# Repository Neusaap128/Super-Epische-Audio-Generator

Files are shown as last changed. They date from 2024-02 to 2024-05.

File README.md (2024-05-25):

**CubeIDEProject:** Deze bevat de code die we op de dev board geschreven hebben voor we overschakelde naar de PCB \
**FiltersWavFiles:** Bevat de C-code en de wav files van filters \
**KicadProject:** De technische schema's van onze PCB en hoe we alles hebben aangesloten aan elkaar \
**SEAG_F:** De implementatie op de STM32F722RC (wat we uitendelijk gebruikt hebben) \
**Super Epische Audio Generator:** Bevat Datasheet per onderdeel, PCB benodigheden, Tekst documenten voor Seminarie waar ook het eindverslag van alles staat

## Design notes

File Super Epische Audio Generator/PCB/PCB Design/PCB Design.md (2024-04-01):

- - -

### General

layer 1 GND plane
layer 2 VCC plane, split digital en analog op de PCB, en teken dan een plane me 3v3 digitaal, en 3v3 analog, dan kan onkoppeling met via's. das kei goe gezien!

### Power Supply

```mermaid

flowchart LR
supply("5V Supply")
digital("Digital Supply")
analog3("Analog 3V3 Supply")
analog2("Analog 2V Supply")
supply-- 3V3 LDO \n Voltage Regulator --> digital
supply -- 3V3 LDO \n Voltage Regulator --> analog3
analog3 -- 2V5 LDO \n Voltage Regulator --> analog2
```

### Audio Filtering

Use difference IC's for input and output buffers.

### Codec

HPSEL = 10 JD2

Single ended Non inverting input PGA should be connected to VMID.
(Closed when LMP2=0 & LMP3=0, or when muted)

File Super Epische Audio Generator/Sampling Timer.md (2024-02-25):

- - -

Sampling Rate counter example

$f_s$ = 44.000Khz
$T_s$ = 1/f = 22.72µs = 22727.27ns

Prescaler bus = /1
Prescaler timer = /1 

Timer Clock $f_{clk}$ = 170Mhz
Timer period $T_{clk}$ = 5.88ns

clockstrikes = $\frac{T_s}{T_{clk}} = \frac{f_{clk}}{T_s}$ = 3864

--- Will's notes ---

CLK settings
200MHZ
APB1 pre /4
APB2 pre /2
=> timer 1 clock = 100MHz

calculation
100MHz => periode van 10ns
elke 500ms
500ms / 10ns = 50 000 000
50 000 000 => count value

48MHz => 21ns
na 5sec
5000 / 21ns = 238 095 238

Prescaler (ni nodig as u waarde in die variable past)
in 1 seconde 100 000 000 pulses
in 1 seconde      10 000 pulses    ( / 10000 ) = prescaler

autoreload aanzette hangt af van applicatie
couter mode => down
prescaler 0
counter period  = 50000 - 1 (0 is ook een waarde)
(zorgen dat in een 32bit register past)

turn NVIC on in timer menu en system core tab

SYS timebase source timer 1

code
HAL_TIM_Base_Start_IT (vergeet IT ni !!!)

if (htim->Instance == TIM2) {
     //Plaats uw code hier
}

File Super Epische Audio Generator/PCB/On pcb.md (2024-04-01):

- [ ] ledbar
- [ ] led-select bar
- [ ] togel
- [ ] codec
- [ ] STM 
- [ ] voltage regulator
- [ ]

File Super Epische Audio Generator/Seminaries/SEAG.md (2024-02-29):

- - -

### Onderwerp 
We gaan voor ons IB3 project een audio effect generator maken. We zijn 3 elektronica-ICT studenten, we bouwen dit project verder op onze reeds vergaarde kennis van een voorgaand vak namelijk Digital Signal Processing (DSP). We gaan een audio signaal binnen lezen, dit signaal dan vervormen aan de hand van filters en terug naar buiten brengen via een audio jack.

### Probleem omschrijving
Niet gemoduleerde instrument klanken kunnen eentonig klinken. Om dit op te lossen gaan we aan de hand van DSP de audio transformeren. We willen een gemakkelijke user interface hebben waarmee je eenvoudig de effecten kunt instellen. 

Wanneer de audio luid en duidelijk hoorbaar is door een speaker, na vervorming, kunnen we spreken van een geslaagd project!

### Technische beschrijving
Voor de audio wordt ingelezen wordt deze gebuffered en gefiltert. De audio digitaliseren we via een codec, deze sampled de audio naar 24 bit waarden. Deze worden vervolgens doorgestuurd naar een STM32 controller via I²S verbinding. De codec wordt ingesteld via I²C. De STM32 microcontroller doet DSP om de audio te vervormen. Vervolgens word de vervormende digitale audio terug gestuurd naar de codec, dia het via een Digital Analog Converter (DAC) terug omzet naar een hoorbaar electrisch signaal.

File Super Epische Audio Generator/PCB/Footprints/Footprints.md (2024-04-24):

- - -

### Power Supply

3.3V LDO voltage regulator:
https://www.mouser.be/ProductDetail/Diodes-Incorporated/AP7365-33YG-13?qs=abZ1nkZpTuOMWfgz6BLgPQ%3D%3D

2.5V LDO voltage regulator (Not used):
https://www.mouser.be/ProductDetail/Diodes-Incorporated/AP7365-25YG-13?qs=abZ1nkZpTuOUTso75Vvnyg%3D%3D

ESD Protection diode 6.5V
https://www.mouser.be/ProductDetail/Diodes-Incorporated/SMAJ6.5A-13-F?qs=gaDBXWSqsDCMFmRk5%252BbksQ%3D%3D

Reverse voltage shotkey diode
https://www.mouser.be/ProductDetail/Panjit/SX33L_R1_00001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.
### MCU

stm32 g431RB:
https://www.mouser.be/ProductDetail/STMicroelectronics/STM32G431RBT3?qs=GedFDFLaBXGyvb87LV0VhQ%3D%3D

STM32 F722RCT6:
https://www.mouser.be/ProductDetail/STMicroelectronics/STM32F722RCT6?qs=Mv7BduZupUiR0Y60TnwX8g%3D%3D

Crystal:
https://www.mouser.be/ProductDetail/Diodes-Incorporated/FW2500025Z?qs=Rp3RbKSfAt1J3JBNemv8gQ%3D%3D

### Audio Filtering

Audio op-amp
https://www.mouser.be/ProductDetail/Texas-Instruments/LM833DR?qs=Ze4%2FuFuz19LM5Pd0zMa%2Fjg%3D%3D 

Audio codec
https://www.digikey.be/en/products/detail/cirrus-logic-inc/WM8960CGEFL-V/5036712

# IO

Shift Register
https://www.mouser.be/ProductDetail/Nexperia/74HC595D-Q100118?qs=1sbE9T7hb3auqb4IeRpHgw%3D%3D

Screw terminal 3
https://www.mouser.be/ProductDetail/TE-Connectivity/282834-3?qs=A%252Bip%252BNCYi6M69kAjqV38yA%3D%3D

### Miscellaneous

47uF cap
https://www.vishay.com/docs/40189/t58.pdf

- Weerstanden smd 0805
- Caps smd 0805
- Shift registers 
- Ledjes THT en SMD
- Micro usb-b  female connector
- Feritte bead 
- Jumper cables
- St link programmer
- Male headers
- Audio female jacks
- Pot meters
- Toggles
- SPDT 
- Eigen PCB

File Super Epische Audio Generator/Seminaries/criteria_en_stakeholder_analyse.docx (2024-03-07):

# Audio Effect Generator

Doelstelling:

We gaan een audio effect generator maken met zelf gecreëerde effecten. We gaan simpel beginnen met een audio input via AUX binnen te lezen. Het inkomend audiosignaal via een STM controller bewerken en dan terug via een AUX naar buiten brengen. Op de output kan dan een speaker worden aangesloten om het bewerkt signaal te beluisteren.

Onze minimum criteria zijn:

- Audio input/output via AUX binnen lezen.
- ADC en DAC .
- Aansturen via een controller developer board.
- I / O knoppen om de gecreëerde effecten aan te sturen.
- Zelf de volgende effecten creëren:
- Bass regelen
- Treble
- Delay
- chorus

Als we klaar zijn met de minimum criteria gaan we ons project nog uitbereide als volgt:

- Een PCB zelf maken
- Meerdere inputs
- Nog extra effecten creëren:
  - Reverb
  - Distortion
  - Loop
  - Wahwah
- Betere DAC/ADC codec

Beknopte stakeholder analyse:

We gaan de stakeholder analyse doen aan de hand van volgende vier vragen:

- Wie zijn je stakeholders en wat willen ze?

Onze stakeholder is meneer Pauwels (key stakeholder). Hij zal ons opvolgen en begeleiden doorheen het semester. Hij wilt dat we op een gelijk tempo elke week in het labo vooruitgang boeken om zo tot een afgewerkt product te komen. De uitgebreide stakeholders (keep satisfied) is ook nog de jury die ons gaat evalueren tijdens onze demo/presentatie. Doordat zij alleen onze eind versie zullen zien tijdens onze demo is het voornamelijk belangrijk dat we tegen dan een mooi verzorgde demo kunnen geven.

Uiteraard zijn wij als developers ook key stakeholders. Bij ons is het belangrijk dat we tegen de uiterste deadline onze minimum criteria sowieso kunnen laten zien en (hopelijk) ook enkele uitbereidingen. Dit willen we bereiken door als team wekelijks progressie te maken en duidelijk te communiceren aan de hand van scrum meetings tijdens onze 4u in het labo en onze meetings op zondag.

- Waarom willen ze dit?

Meneer Pauwels wilt dit door dat hij vooruitgang wilt zien tijdens onze project uren iedere week, doordat hij ook een cijfer geeft op onze permanente evaluatie.

De jury gaat alleen ons eind project zien dus voor hen is het alleen belangrijk dat we een mooi eindresultaat hebben.

Wij als developers zijn begaan met heel het project dus willen een goed verloop en eindresultaat.

- Hoe kunnen ze invloed uitoefenen op je traject?

Meneer Pauwels kan invloed uitoefenen door ons raad te geven doorheen het semester. Hij bepaald ook onze permanente evaluatie en ons eind resultaat.

De jury heeft alleen invloed op ons eind resultaat.

Wij hebben invloed over heel het traject. Door de opties dat we kiezen en onze werkhouding doorheen het traject.

- Hoe kan je jouw stakeholders zo goed mogelijk managen?

Meneer Pauwels kunnen we managen door zo goed mogelijk met hem te communiceren doorheen het traject.

De jury kunnen we moeilijk managen doordat we nog niet weten wie er in de jury zou zitten. We kunnen hen enkel managen door een goed voorbereide presentatie te geven en hun op het moment van onze demo om ver te blazen.

Wij kunnen ons zelf managen door goede afspraken te maken en duidelijk onderling te communiceren. Zo komen we al elke week 4u samen tijdens onze project uren en dan bellen we ook op regelmatige basis in Discord met mekaar.

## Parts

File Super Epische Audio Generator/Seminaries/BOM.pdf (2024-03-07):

# BOM

## Power Supply

3.3V LDO voltage regulator: https://www.mouser.be/ProductDetail/Diodes-Incorporated/AP7365-33YG-13?qs=abZ1nkZpTuOMWfgz6BLgPQ%3D%3D (https://www.mouser.be/ProductDetail/Diodes-Incorporated/AP7365-33YG-13?qs=abZ1nkZpTuOMWfgz6BLgPQ%3D%3D)

2.5V LDO voltage regulator (Not used): https://www.mouser.be/ProductDetail/Diodes-Incorporated/AP7365-25YG-13?qs=abZ1nkZpTuOUTso75Vvnyg%3D%3D (https://www.mouser.be/ProductDetail/Diodes-Incorporated/AP7365-25YG-13?qs=abZ1nkZpTuOUTso75Vvnyg%3D%3D)

## MCU

stm32 g431RB:
https://www.mouser.be/ProductDetail/STMicroelectronics/STM32G431RBT3?qs=GedFDFLaBXGyvb87LV0VhQ%3D%3D (https://www.mouser.be/ProductDetail/STMicroelectronics/STM32G431RBT3?qs=GedFDFLaBXGyvb87LV0VhQ%3D%3D)

STM32 F722RCT6:
https://www.mouser.be/ProductDetail/STMicroelectronics/STM32F722RCT6?qs=Mv7BduZupUiR0Y60TnwX8g%3D%3D (https://www.mouser.be/ProductDetail/STMicroelectronics/STM32F722RCT6?qs=Mv7BduZupUiR0Y60TnwX8g%3D%3D)

## Audio Filtering

Audio op-amp
https://www.mouser.be/ProductDetail/Texas-Instruments/LM833DGKR?qs=Ze4%2FuFuz19JOpjm8ASDMUA%3D%3D (Footprint not downloaded (https://www.mouser.be/ProductDetail/Texas-Instruments/LM833DGKR?qs=Ze4%2FuFuz19JOpjm8ASDMUA%3D%3D) yet)

Audio codec

## Miscellaneous

Weerstanden smd 0805
Caps smd 0805
Shift registers
Ledjes THT en SMD
Micro usb-b female connector Feritte bead

Jumper cables
St link programmer
Male headers
Audio female jacks
Pot meters
Toggles
SPDT
Eigen PCB

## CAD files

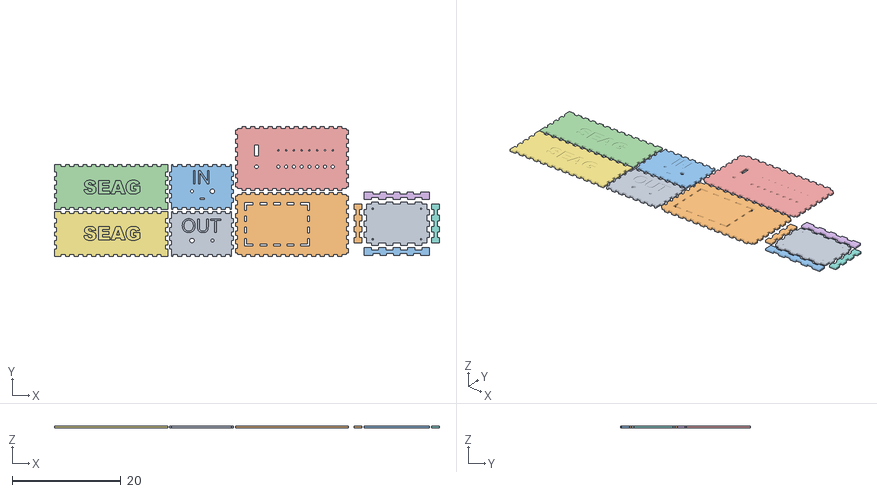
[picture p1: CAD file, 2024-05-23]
Super Epische Audio Generator/2D tekeningen/SEAGdoos.obj
70.7 x 23.9 x 0.4

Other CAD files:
Super Epische Audio Generator/2D tekeningen/SEAGDoos.dwg
Super Epische Audio Generator/2D tekeningen/SEAG_doos.dxf

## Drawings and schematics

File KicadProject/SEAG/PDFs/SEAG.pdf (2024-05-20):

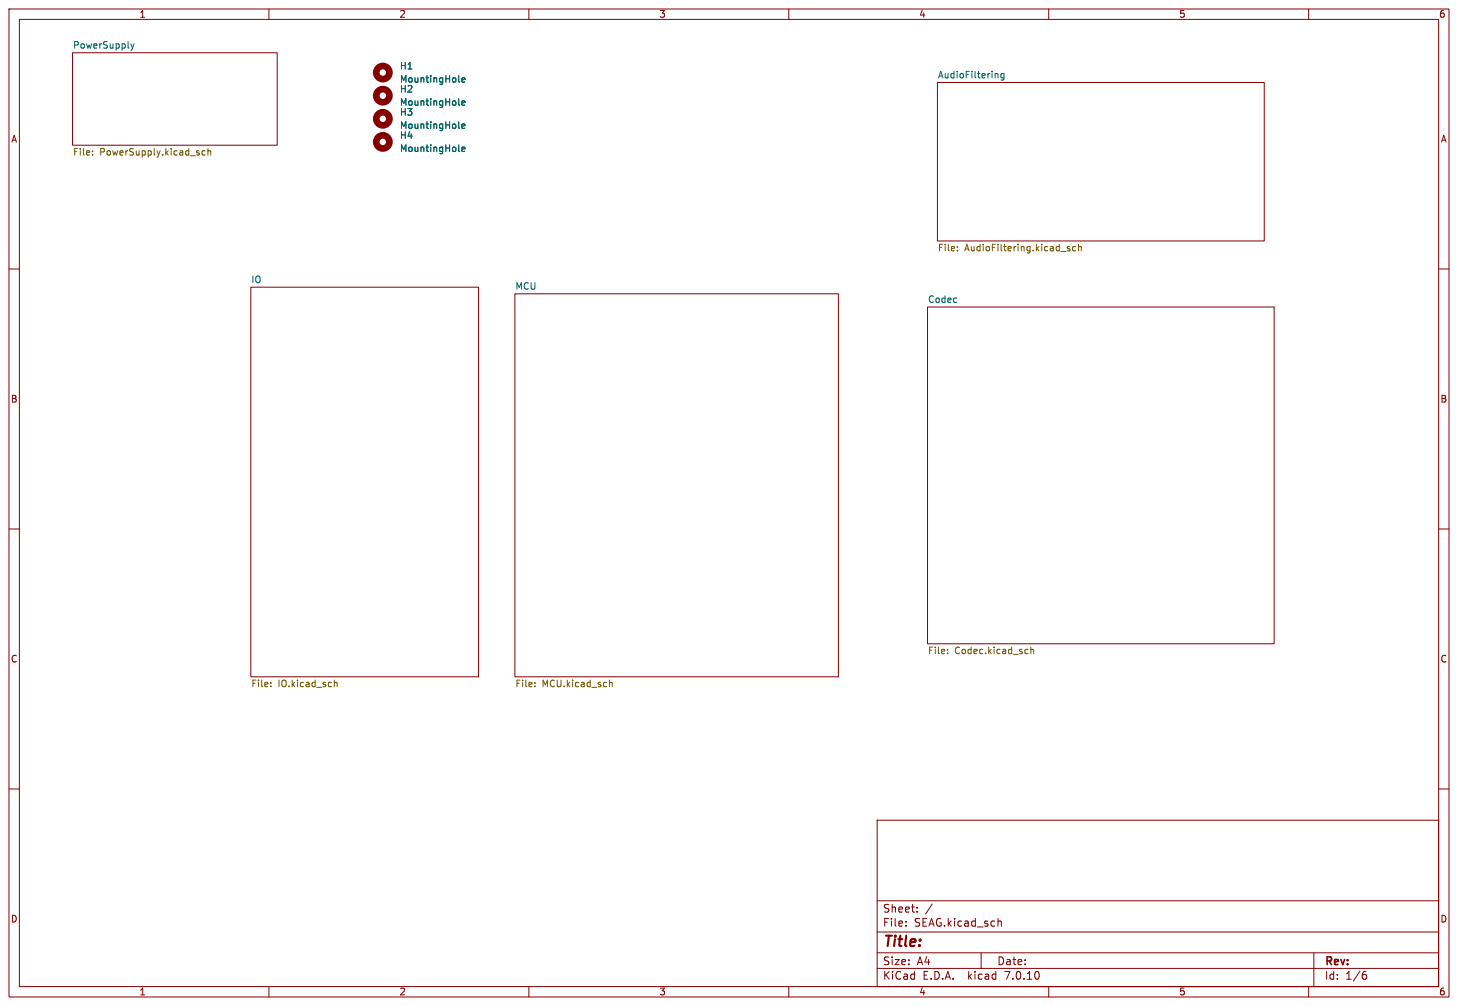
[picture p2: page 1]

H1 MountingHole H3 MountingHole H4 MountingHole H2 MountingHole

AudioFiltering File: AudioFiltering.kicad_sch MCU

Id: 1/6 Title: File: SEAG.kicad_sch Sheet: /

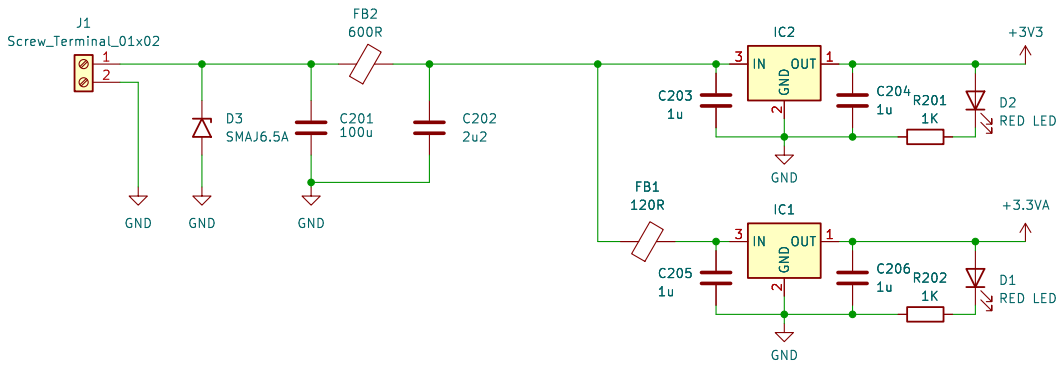
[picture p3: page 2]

File: PowerSupply.kicad_sch Sheet: /PowerSupply/
Id: 2/6 Title: Power Supply

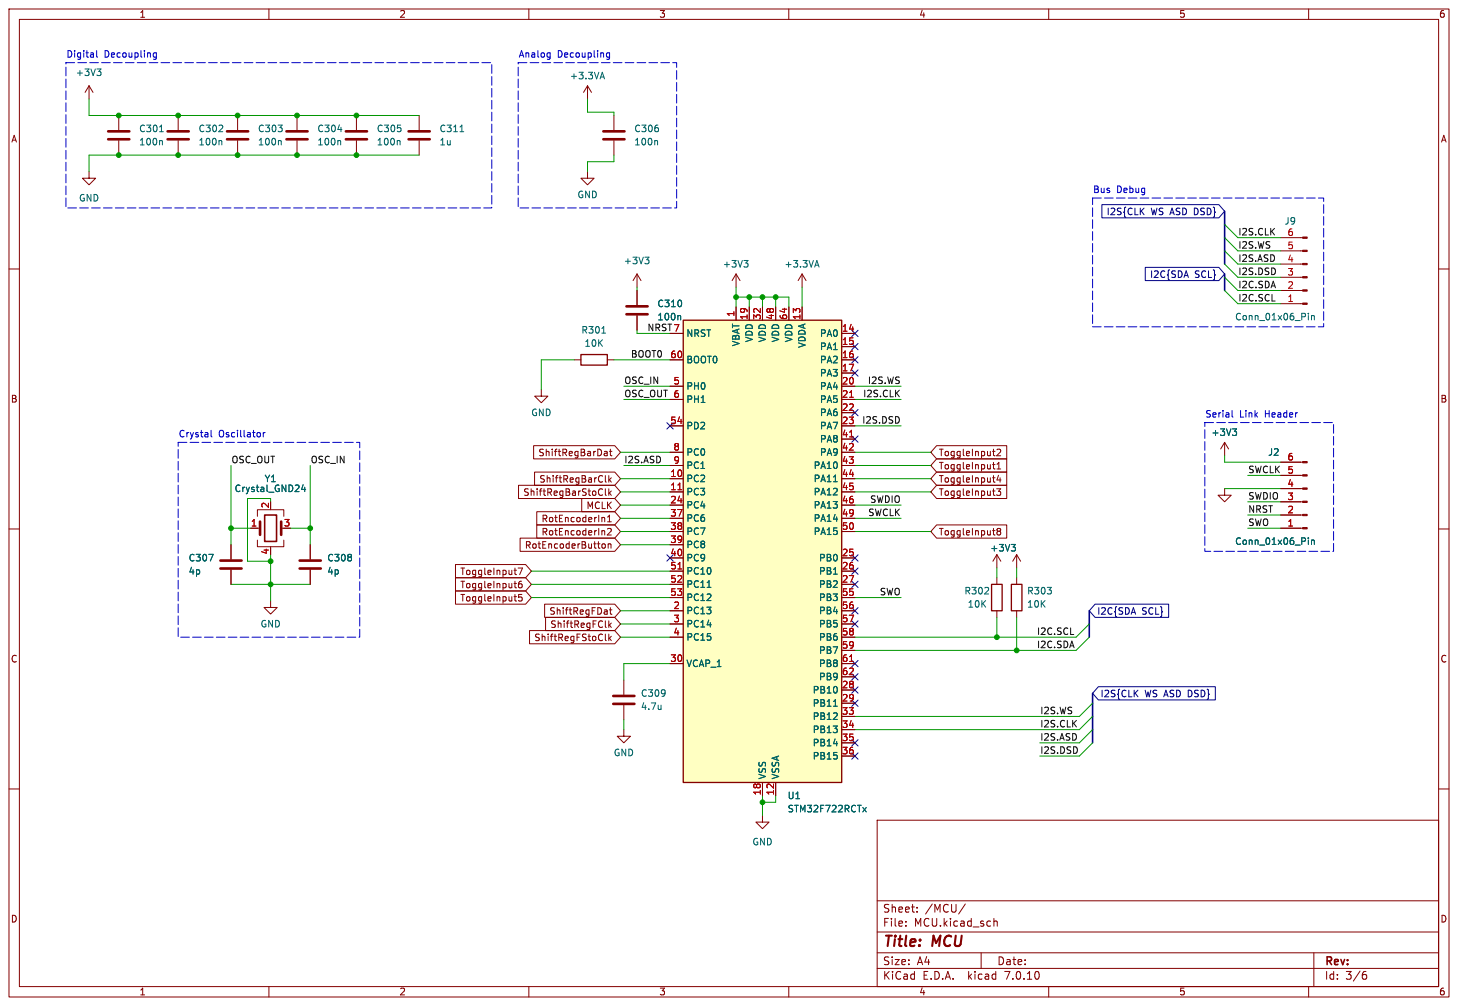
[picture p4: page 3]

I2S{CLK WS ASD DSD}

1 PC2 10 PC3 11 VSSA 12 VDDA 13 PA0 14 PA1 15 PA2 16 PA3 17 VSS 18 VDD 19 PC13 2 PA4 20 PA5 21 PA6 22 PA7 23 PC4 24 PB0 25 PB1 26 PB2 27 PB10 28 PB11 29 PC14 3 VCAP_1 30 VDD 32 PB12 33 PB13 34 PB14 35 PB15 36 PC6 37 PC7 38 PC8 39 PC15 4 PC9 40 PA8 41 PA9 42 PA10 43 PA11 44 PA12 45 PA13 46 VDD 48 PA14 49 PH0 5 PA15 50 PC10 51 PC11 52 PC12 53 PD2 54 PB3 55 PB4 56 PB5 57 PB6 58 PB7 59 PH1 6 BOOT0 60 PB8 61 PB9 62 VDD 64 NRST 7 PC0 8 PC1 9 U1STM32F722RCTx

1 PC2 10 PC3 11 VSSA 12 VDDA 13 PA0 14 PA1 15 PA2 16 PA3 17 VSS 18 VDD 19 PC13 2 PA4 20 PA5 21 PA6 22 PA7 23 PC4 24 PB0 25 PB1 26 PB2 27 PB10 28 PB11 29 PC14 3 VCAP_1 30 VDD 32 PB12 33 PB13 34 PB14 35 PB15 36 PC6 37 PC7 38 PC8 39 PC15 4 PC9 40 PA8 41 PA9 42 PA10 43 PA11 44 PA12 45 PA13 46 VDD 48 PA14 49 PH0 5 PA15 50 PC10 51 PC11 52 PC12 53 PD2 54 PB3 55 PB4 56 PB5 57 PB6 58 PB7 59 PH1 6 BOOT0 60 PB8 61 PB9 62 VDD 64 NRST 7 PC0 8 PC1 9 +3V3

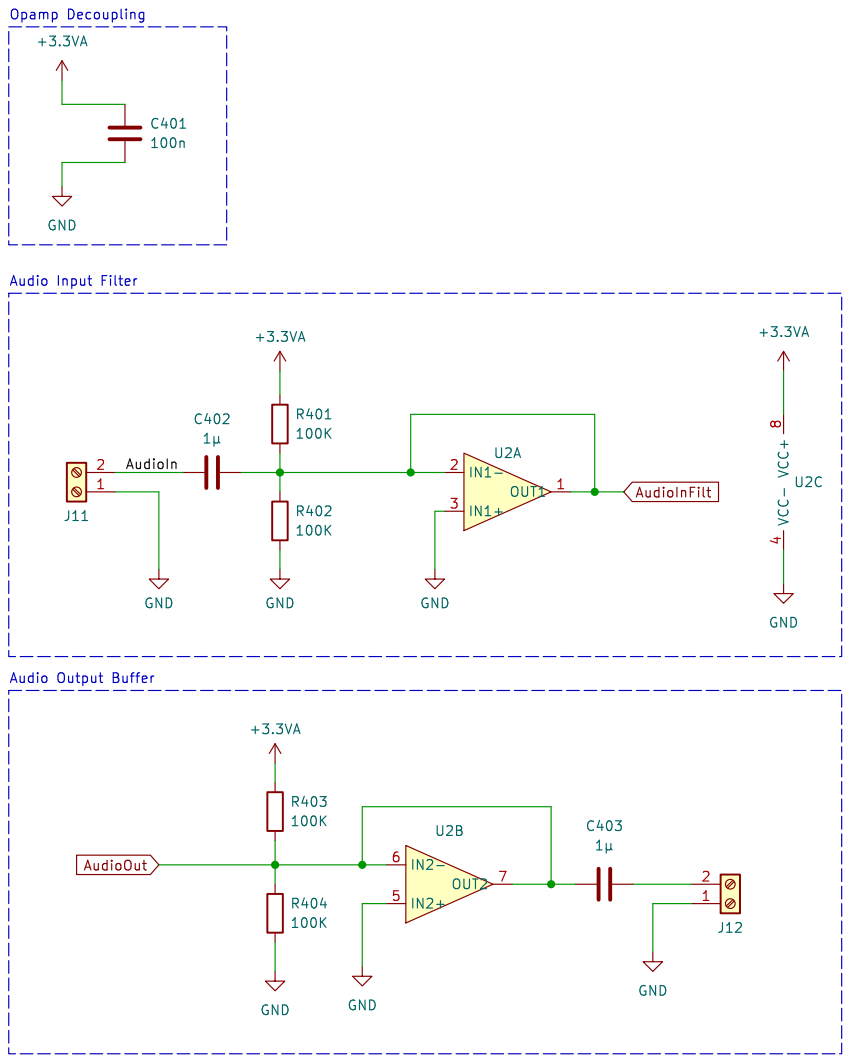
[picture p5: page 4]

Id: 4/6 Title: File: AudioFiltering.kicad_sch Sheet: /AudioFiltering/ VCC- 4 VCC+

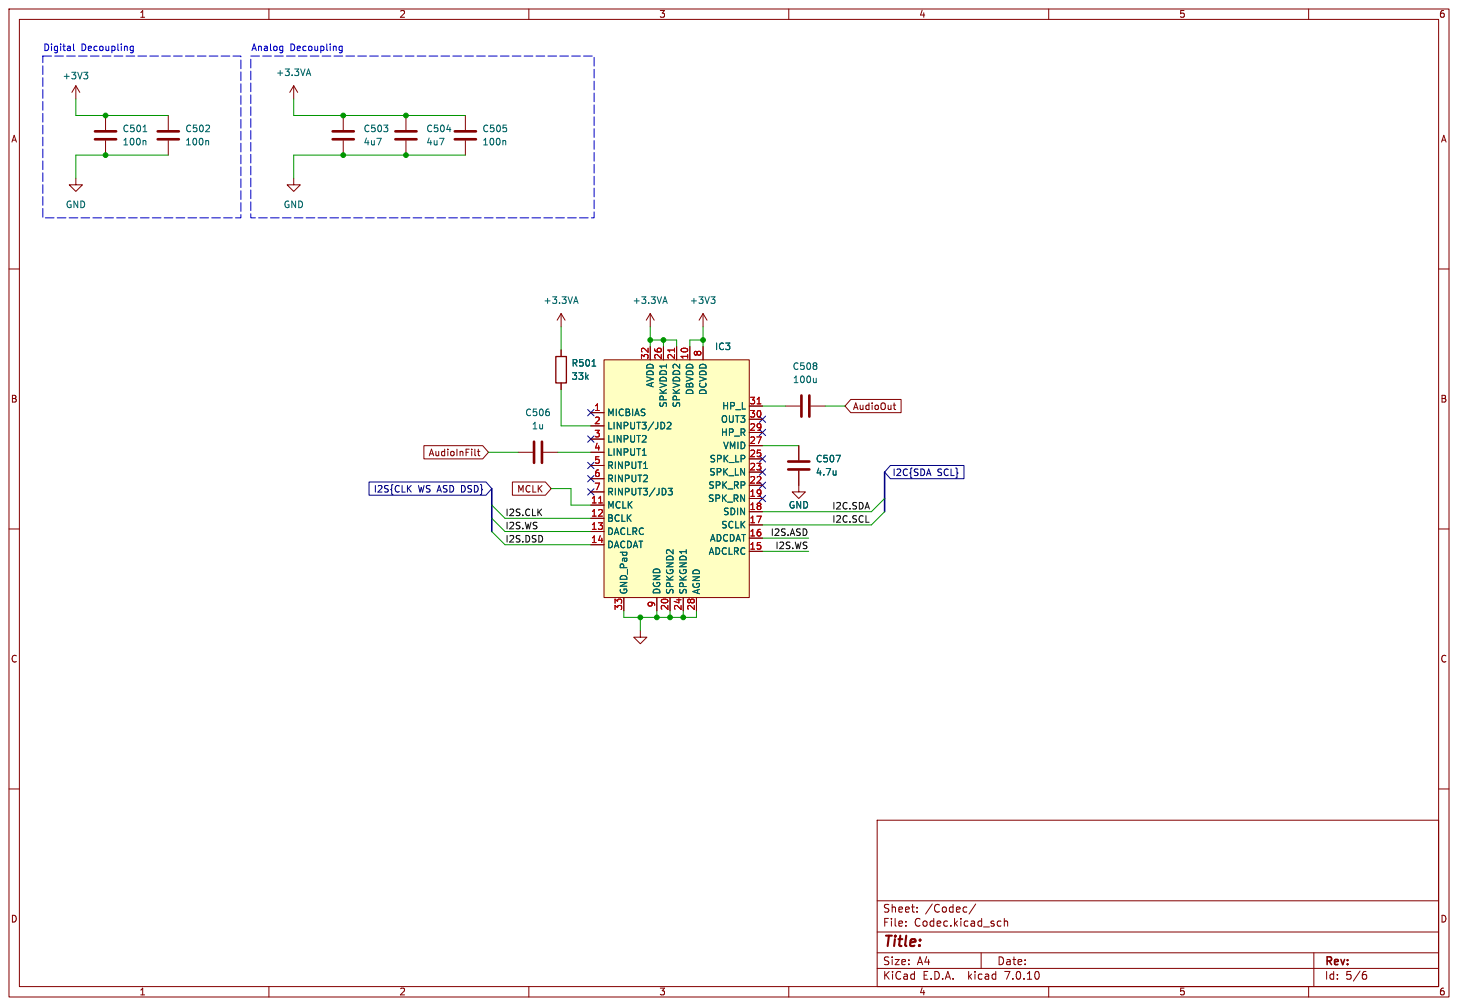
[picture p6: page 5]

Id: 5/6 Title: File: Codec.kicad_sch Sheet: /Codec/

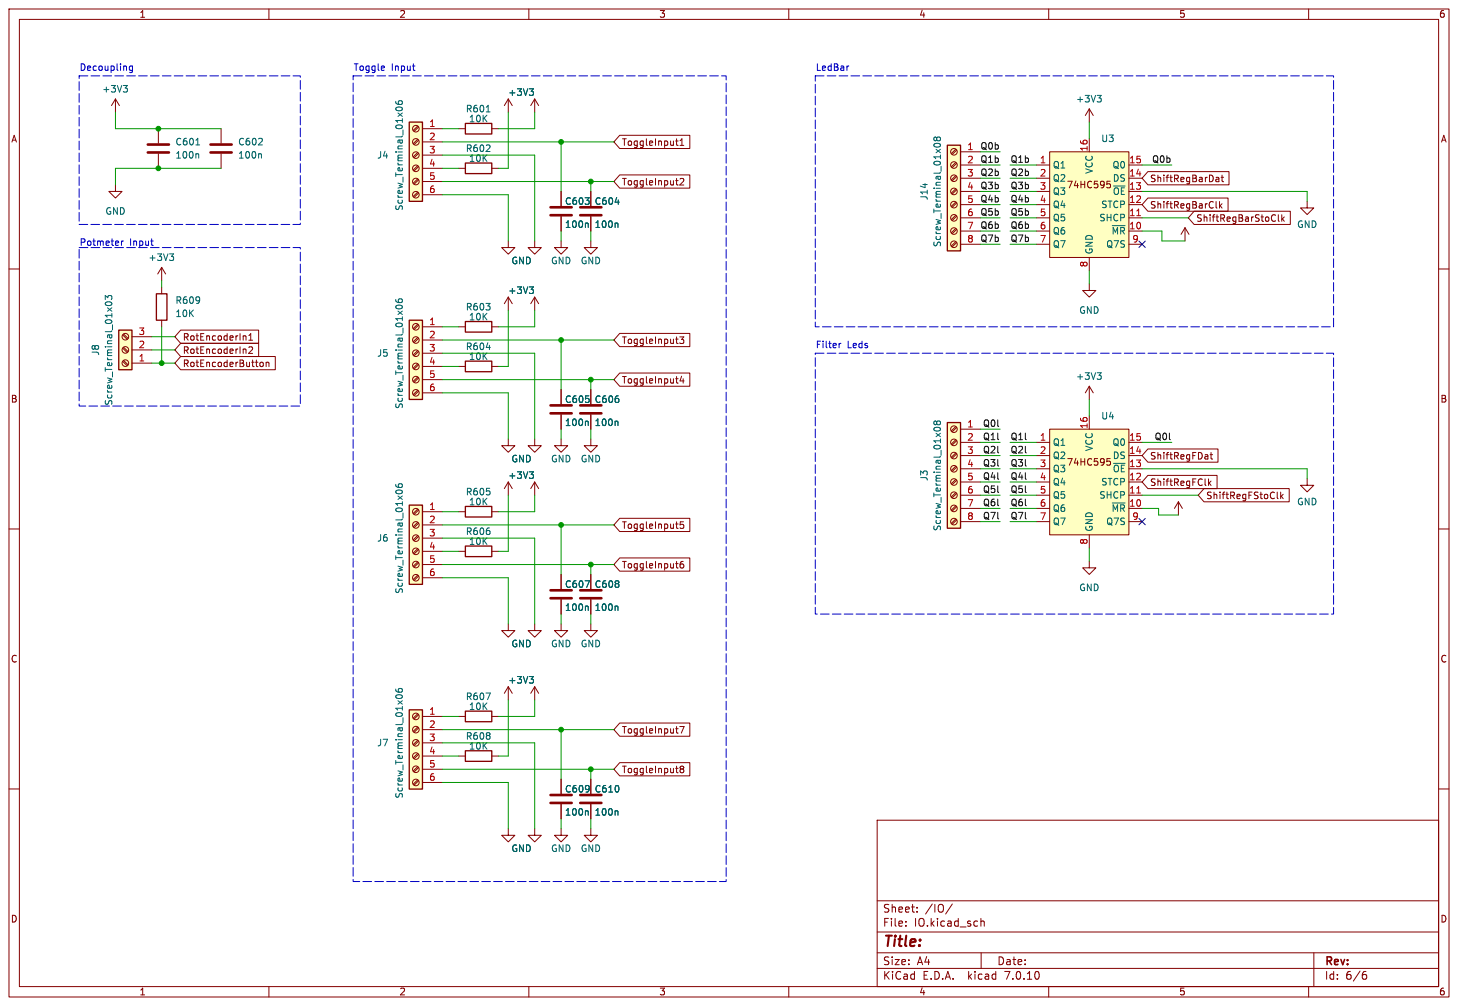
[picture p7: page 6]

Id: 6/6 Title: File: IO.kicad_sch Sheet: /IO/

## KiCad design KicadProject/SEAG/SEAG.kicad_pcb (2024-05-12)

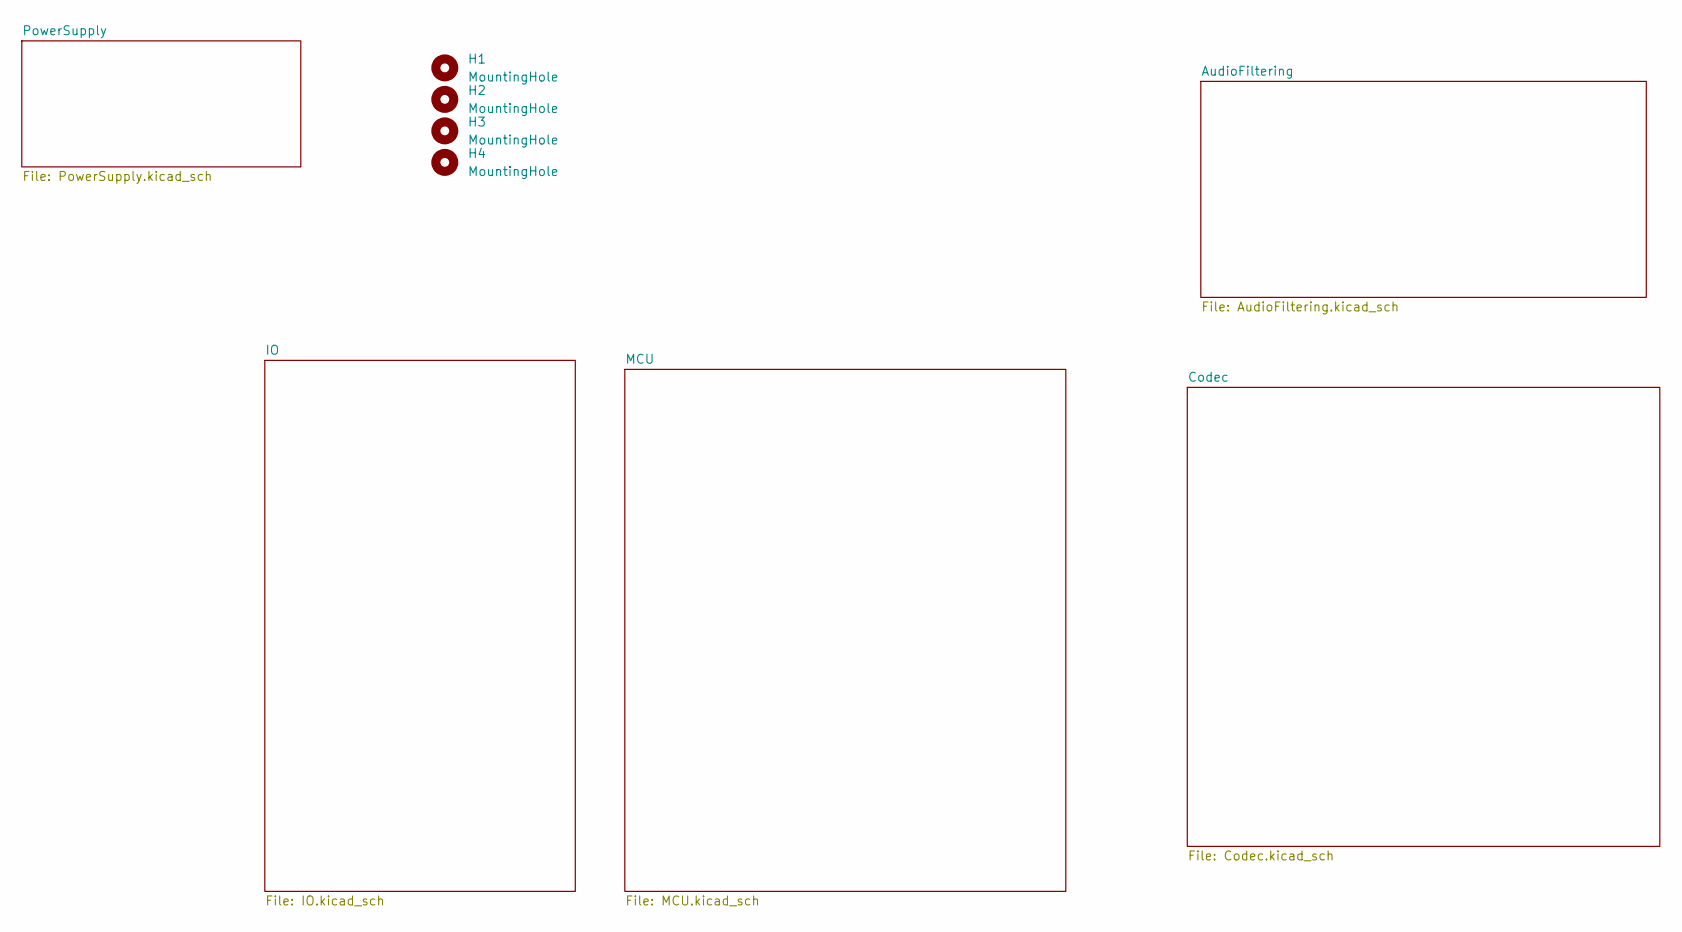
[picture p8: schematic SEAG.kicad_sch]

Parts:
H1, H2, H3, H4: MountingHole; MountingHole_3mm

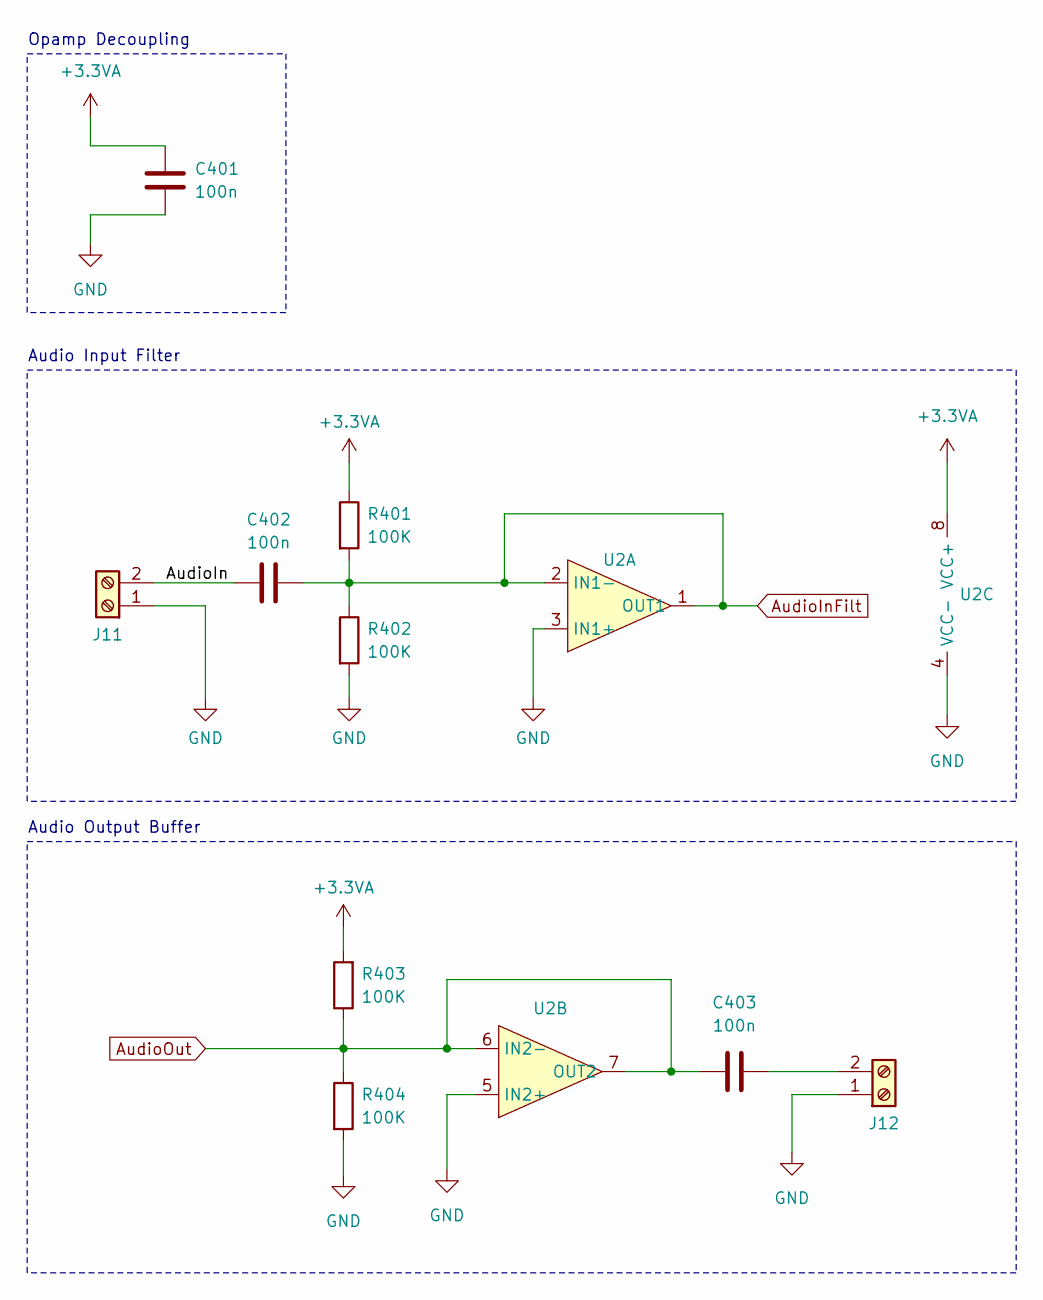
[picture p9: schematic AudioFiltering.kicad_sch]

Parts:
C401, C402, C403: 100n; C_0805_2012Metric
J11, J12: Screw_Terminal_01x02; TerminalBlock_Phoenix_MKDS-1,5-2_1x02_P5.00mm_Horizontal
R401, R402, R403, R404: 100K; R_0805_2012Metric
U2: SOIC127P600X175-8N

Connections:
+3.3VA: C401.1, R401.1, R403.2, U2.8 (VCC+); also elsewhere on the board
/AudioFiltering/AudioIn: C402.1, J11.2
AudioInFilt: C402.2, R401.2, R402.1, U2.1 (OUT1), U2.2 (IN1-); also elsewhere on the board
AudioOut: C403.1, R403.1, R404.1, U2.6 (IN2-), U2.7 (OUT2); also elsewhere on the board
GND: C401.2, J11.1, J12.1, R402.2, R404.2, U2.3 (IN1+), U2.4 (VCC-), U2.5 (IN2+); also elsewhere on the board
unnamed: C403.2, J12.2

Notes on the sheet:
Opamp Decoupling
Audio Input Filter
Audio Output Buffer

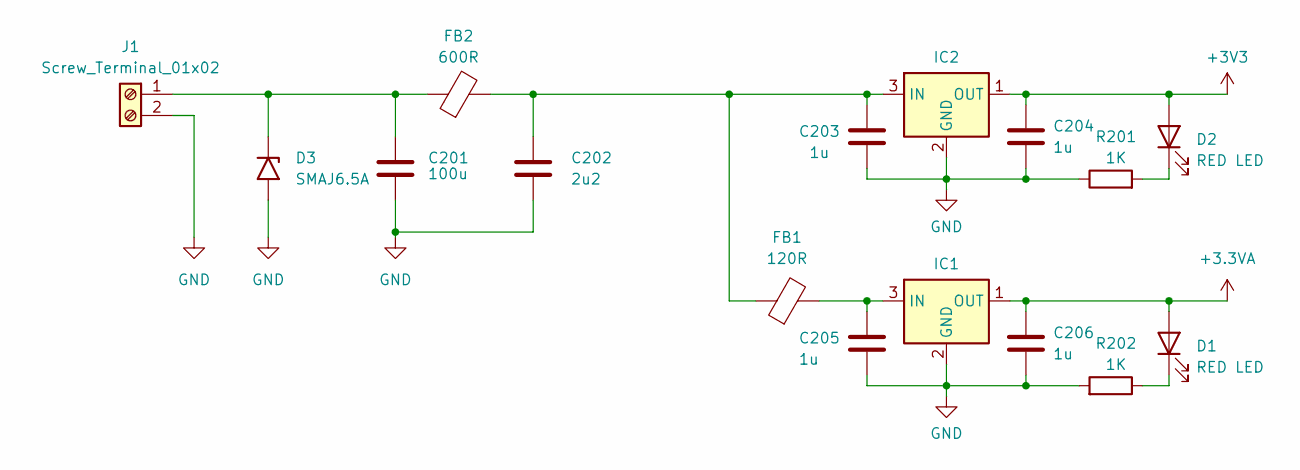
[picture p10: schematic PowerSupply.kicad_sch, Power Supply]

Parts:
C201: 100u; C_0805_2012Metric
C202: 2u2; C_0805_2012Metric
C203, C204, C205, C206: 1u; C_0805_2012Metric
D1, D2: RED LED; LED_0805_2012Metric
D3: SMAJ6.5A; D_SMA
FB1: 120R; L_0805_2012Metric
FB2: 600R; L_0805_2012Metric
IC1, IC2: AP736533YG13
J1: Screw_Terminal_01x02; TerminalBlock_Phoenix_MKDS-1,5-2_1x02_P5.00mm_Horizontal
R201, R202: 1K; R_0805_2012Metric

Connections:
+3.3VA: C206.1, D1.2 (A), IC1.1 (OUT); also elsewhere on the board
+3V3: C204.1, D2.2 (A), IC2.1 (OUT); also elsewhere on the board
GND: C201.2, C202.2, C203.2, C204.2, C205.2, C206.2, D3.2 (A2), IC1.2 (GND), IC1.4 (GND), IC2.2 (GND), IC2.4 (GND), J1.2, R201.1, R202.2; also elsewhere on the board
unnamed: D1.1 (K), R202.1
unnamed: D2.1 (K), R201.2
unnamed: C201.1, D3.1 (A1), FB2.1, J1.1
unnamed: C205.1, FB1.2, IC1.3 (IN)
unnamed: C202.1, C203.1, FB1.1, FB2.2, IC2.3 (IN)

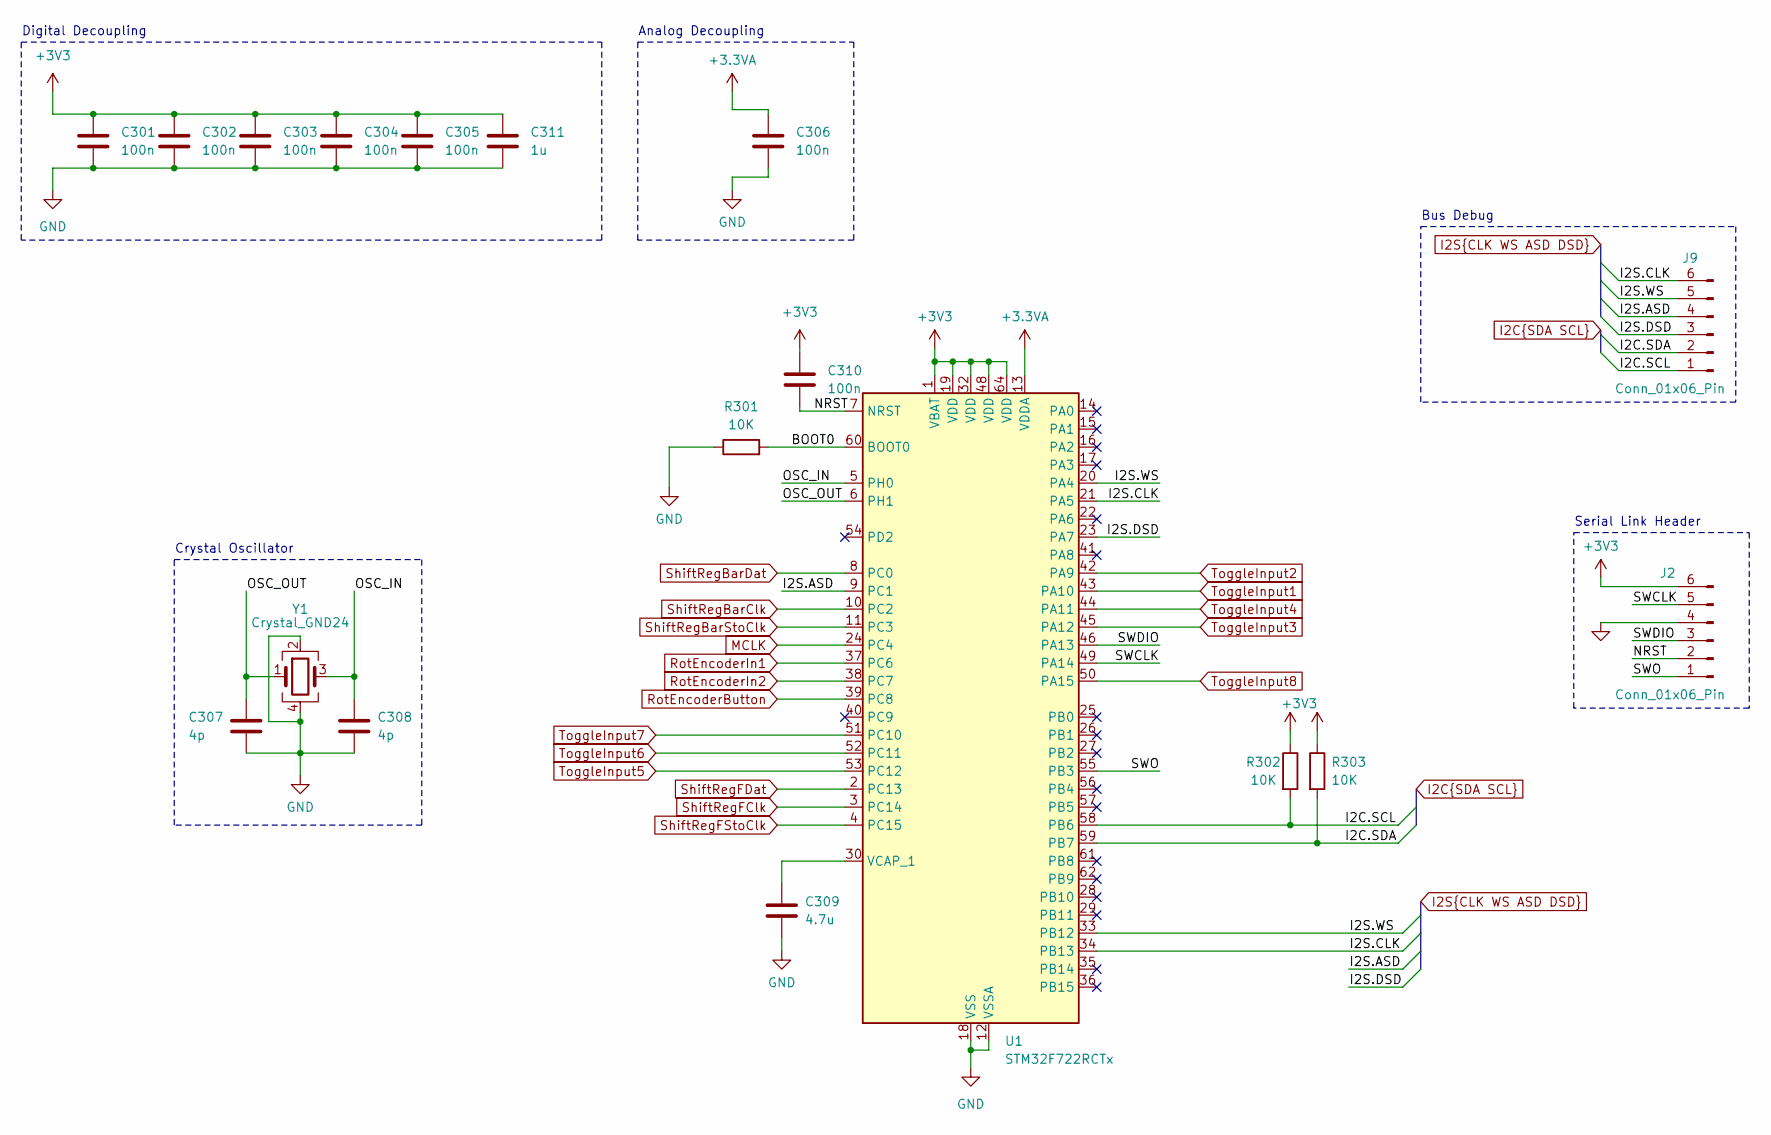
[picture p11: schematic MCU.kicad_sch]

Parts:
C301, C302, C303, C304, C305, C306, C310: 100n; C_0805_2012Metric
C307, C308: 4p; C_0805_2012Metric
C309: 4.7u; C_0805_2012Metric
C311: 1u; C_0805_2012Metric
J2, J9: Conn_01x06_Pin; PinHeader_1x06_P2.54mm_Vertical
R301, R302, R303: 10K; R_0805_2012Metric
U1: STM32F722RCTx; LQFP-64_10x10mm_P0.5mm
Y1: Crystal_GND24; FW2500025Z

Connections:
+3.3VA: C306.1, U1.13 (VDDA); also elsewhere on the board
+3V3: C301.1, C302.1, C303.1, C304.1, C305.1, C310.1, C311.1, J2.6, R302.1, R303.1, U1.1 (VBAT), U1.19 (VDD), U1.32 (VDD), U1.48 (VDD), U1.64 (VDD); also elsewhere on the board
/MCU/BOOT0: R301.2, U1.60 (BOOT0)
/MCU/NRST: C310.2, J2.2, U1.7 (NRST)
/MCU/OSC_IN: C308.1, U1.5 (PH0), Y1.3
/MCU/OSC_OUT: C307.1, U1.6 (PH1), Y1.1
/MCU/SWCLK: J2.5, U1.49 (PA14)
/MCU/SWDIO: J2.3, U1.46 (PA13)
/MCU/SWO: J2.1, U1.55 (PB3)
GND: C301.2, C302.2, C303.2, C304.2, C305.2, C306.2, C307.2, C308.2, C309.2, C311.2, J2.4, R301.1, U1.12 (VSSA), U1.18 (VSS), U1.31 (VSS), U1.47 (VSS), U1.63 (VSS), Y1.2, Y1.4; also elsewhere on the board
I2C.SCL: J9.1, R302.2, U1.58 (PB6); also elsewhere on the board
I2C.SDA: J9.2, R303.2, U1.59 (PB7); also elsewhere on the board
I2S.ASD: J9.4, U1.9 (PC1); also elsewhere on the board
I2S.CLK: J9.6, U1.21 (PA5), U1.34 (PB13); also elsewhere on the board
I2S.DSD: J9.3, U1.23 (PA7); also elsewhere on the board
I2S.WS: J9.5, U1.20 (PA4), U1.33 (PB12); also elsewhere on the board
MCLK: U1.24 (PC4); also elsewhere on the board
unnamed: C309.1, U1.30 (VCAP_1)
RotEncoderButton: U1.39 (PC8); also elsewhere on the board
RotEncoderIn1: U1.37 (PC6); also elsewhere on the board
RotEncoderIn2: U1.38 (PC7); also elsewhere on the board
ShiftRegBarClk: U1.10 (PC2); also elsewhere on the board
ShiftRegBarDat: U1.8 (PC0); also elsewhere on the board
ShiftRegBarStoClk: U1.11 (PC3); also elsewhere on the board
ShiftRegFClk: U1.3 (PC14); also elsewhere on the board
ShiftRegFDat: U1.2 (PC13); also elsewhere on the board
ShiftRegFStoClk: U1.4 (PC15); also elsewhere on the board
ToggleInput1: U1.43 (PA10); also elsewhere on the board
ToggleInput2: U1.42 (PA9); also elsewhere on the board
ToggleInput3: U1.45 (PA12); also elsewhere on the board
ToggleInput4: U1.44 (PA11); also elsewhere on the board
ToggleInput5: U1.53 (PC12); also elsewhere on the board
ToggleInput6: U1.52 (PC11); also elsewhere on the board
ToggleInput7: U1.51 (PC10); also elsewhere on the board
ToggleInput8: U1.50 (PA15); also elsewhere on the board

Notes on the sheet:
Serial Link Header
Crystal Oscillator
Digital Decoupling
Analog Decoupling
Bus Debug

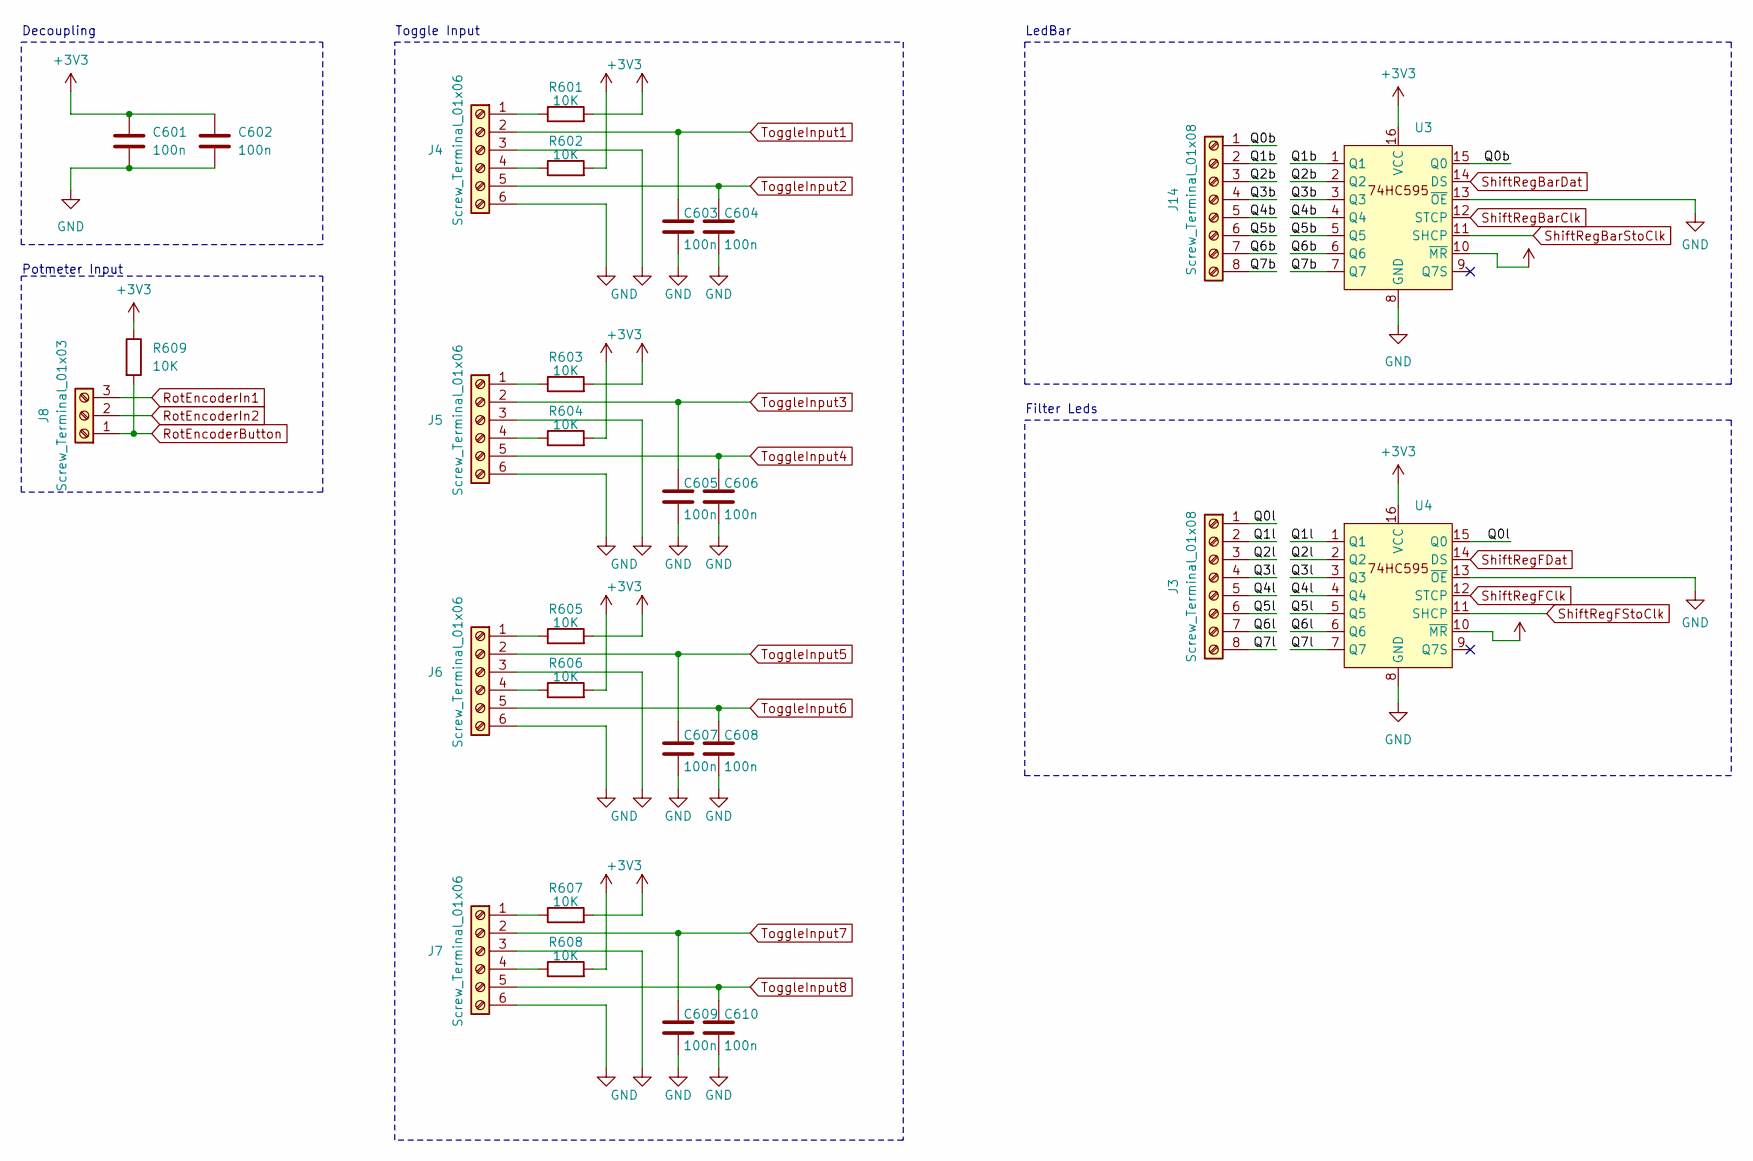
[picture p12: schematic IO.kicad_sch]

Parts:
C601, C602, C603, C604, C605, C606, C607, C608, C609, C610: 100n; C_0805_2012Metric
J3, J14: Screw_Terminal_01x08; 1725711
J4, J5, J6, J7: Screw_Terminal_01x06; 1725698
J8: Screw_Terminal_01x03; 2828343
R601, R602, R603, R604, R605, R606, R607, R608, R609: 10K; R_0805_2012Metric
U3, U4: 74HC595DQ100118

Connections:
+3V3: C601.1, C602.1, R601.2, R602.2, R603.2, R604.2, R605.2, R606.2, R607.2, R608.2, R609.1, U3.10 (~MR), U3.16 (VCC), U4.10 (~MR), U4.16 (VCC); also elsewhere on the board
/IO/Q0b: J14.1, U3.15 (Q0)
/IO/Q0l: J3.1, U4.15 (Q0)
/IO/Q1b: J14.2, U3.1 (Q1)
/IO/Q1l: J3.2, U4.1 (Q1)
/IO/Q2b: J14.3, U3.2 (Q2)
/IO/Q2l: J3.3, U4.2 (Q2)
/IO/Q3b: J14.4, U3.3 (Q3)
/IO/Q3l: J3.4, U4.3 (Q3)
/IO/Q4b: J14.5, U3.4 (Q4)
/IO/Q4l: J3.5, U4.4 (Q4)
/IO/Q5b: J14.6, U3.5 (Q5)
/IO/Q5l: J3.6, U4.5 (Q5)
/IO/Q6b: J14.7, U3.6 (Q6)
/IO/Q6l: J3.7, U4.6 (Q6)
/IO/Q7b: J14.8, U3.7 (Q7)
/IO/Q7l: J3.8, U4.7 (Q7)
GND: C601.2, C602.2, C603.2, C604.2, C605.2, C606.2, C607.2, C608.2, C609.2, C610.2, J4.3, J4.6, J5.3, J5.6, J6.3, J6.6, J7.3, J7.6, U3.8 (GND), U3.13 (~OE), U4.8 (GND), U4.13 (~OE); also elsewhere on the board
unnamed: J4.1, R601.1
unnamed: J4.4, R602.1
unnamed: J5.1, R603.1
unnamed: J5.4, R604.1
unnamed: J6.1, R605.1
unnamed: J6.4, R606.1
unnamed: J7.1, R607.1
unnamed: J7.4, R608.1
RotEncoderButton: J8.1, R609.2; also elsewhere on the board
RotEncoderIn1: J8.3; also elsewhere on the board
RotEncoderIn2: J8.2; also elsewhere on the board
ShiftRegBarClk: U3.12 (STCP); also elsewhere on the board
ShiftRegBarDat: U3.14 (DS); also elsewhere on the board
ShiftRegBarStoClk: U3.11 (SHCP); also elsewhere on the board
ShiftRegFClk: U4.12 (STCP); also elsewhere on the board
ShiftRegFDat: U4.14 (DS); also elsewhere on the board
ShiftRegFStoClk: U4.11 (SHCP); also elsewhere on the board
ToggleInput1: C603.1, J4.2; also elsewhere on the board
ToggleInput2: C604.1, J4.5; also elsewhere on the board
ToggleInput3: C605.1, J5.2; also elsewhere on the board
ToggleInput4: C606.1, J5.5; also elsewhere on the board
ToggleInput5: C607.1, J6.2; also elsewhere on the board
ToggleInput6: C608.1, J6.5; also elsewhere on the board
ToggleInput7: C609.1, J7.2; also elsewhere on the board
ToggleInput8: C610.1, J7.5; also elsewhere on the board

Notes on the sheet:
Filter Leds
LedBar
Decoupling
Potmeter Input
Toggle Input

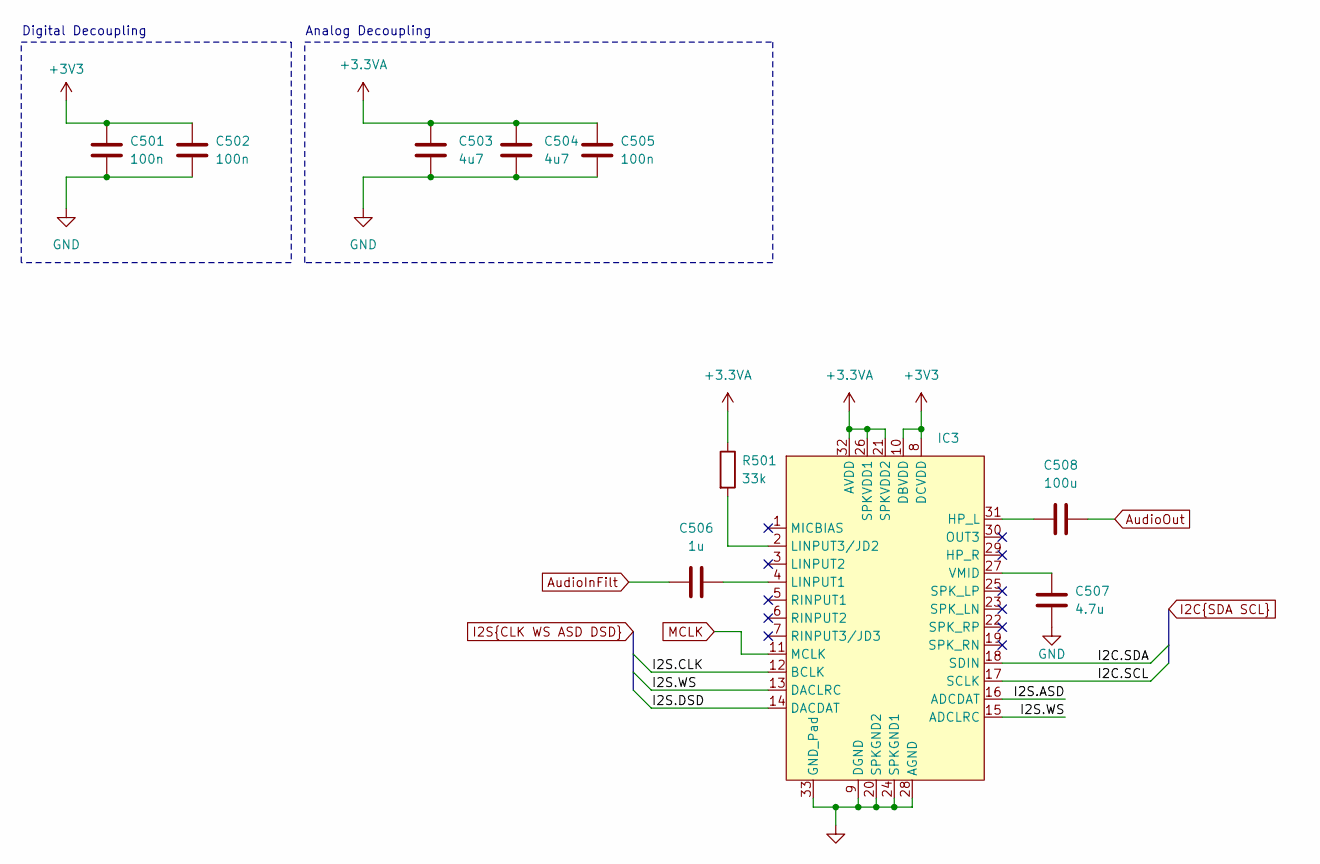
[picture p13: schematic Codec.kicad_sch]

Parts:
C501, C502, C505: 100n; C_0805_2012Metric
C503, C504: 4u7; C_0805_2012Metric
C506: 1u; C_0805_2012Metric
C507: 4.7u; C_0805_2012Metric
C508: 100u; C_0805_2012Metric
IC3: QFN50P500X500X100-33N
R501: 33k; R_0805_2012Metric

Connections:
+3.3VA: C503.1, C504.1, C505.1, IC3.21 (SPKVDD2), IC3.26 (SPKVDD1), IC3.32 (AVDD), R501.1; also elsewhere on the board
+3V3: C501.1, C502.1, IC3.8 (DCVDD), IC3.10 (DBVDD); also elsewhere on the board
AudioInFilt: C506.1; also elsewhere on the board
AudioOut: C508.2; also elsewhere on the board
GND: C501.2, C502.2, C503.2, C504.2, C505.2, C507.2, IC3.9 (DGND), IC3.20 (SPKGND2), IC3.24 (SPKGND1), IC3.28 (AGND), IC3.33 (GND_Pad); also elsewhere on the board
I2C.SCL: IC3.17 (SCLK); also elsewhere on the board
I2C.SDA: IC3.18 (SDIN); also elsewhere on the board
I2S.ASD: IC3.16 (ADCDAT); also elsewhere on the board
I2S.CLK: IC3.12 (BCLK); also elsewhere on the board
I2S.DSD: IC3.14 (DACDAT); also elsewhere on the board
I2S.WS: IC3.13 (DACLRC), IC3.15 (ADCLRC); also elsewhere on the board
MCLK: IC3.11 (MCLK); also elsewhere on the board
unnamed: C508.1, IC3.31 (HP_L)
unnamed: C506.2, IC3.4 (LINPUT1)
unnamed: IC3.2 (LINPUT3/JD2), R501.2
unnamed: C507.1, IC3.27 (VMID)

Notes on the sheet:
Analog Decoupling
Digital Decoupling

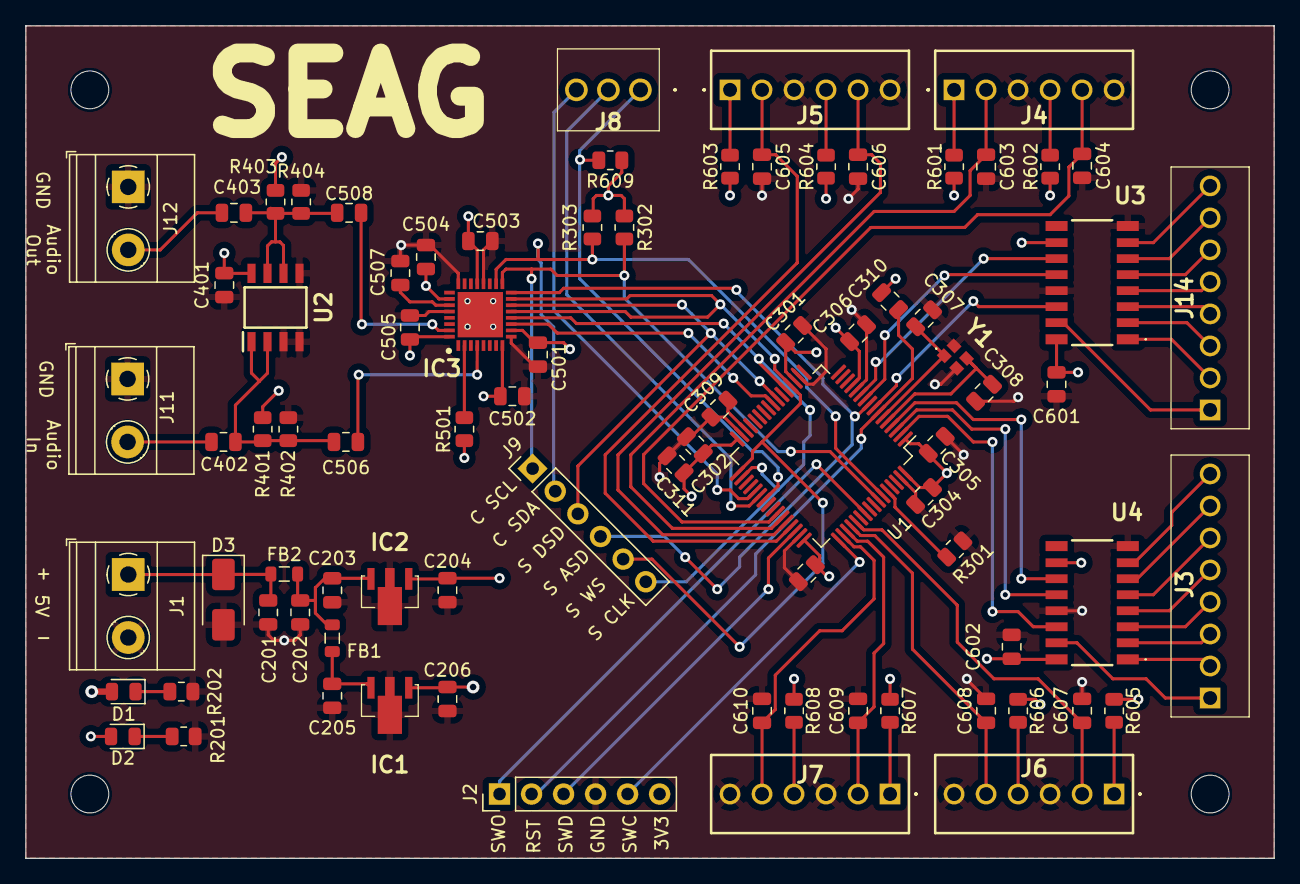
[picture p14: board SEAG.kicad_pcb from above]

Board: 4 copper layers, 99.1 x 66.1 mm, 86 parts (0 on the bottom side), 72 nets.

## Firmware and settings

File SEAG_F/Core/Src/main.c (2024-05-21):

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
/* Includes ------------------------------------------------------------------*/
#include "main.h"


I2C_HandleTypeDef hi2c1;

I2S_HandleTypeDef hi2s1;
I2S_HandleTypeDef hi2s2;
DMA_HandleTypeDef hdma_spi1_tx;
DMA_HandleTypeDef hdma_spi2_rx;

void SystemClock_Config(void);
void PeriphCommonClock_Config(void);
static void MX_GPIO_Init(void);
static void MX_DMA_Init(void);
static void MX_I2C1_Init(void);
static void MX_I2S1_Init(void);
static void MX_I2S2_Init(void);
/* USER CODE BEGIN 0 */

uint32_t previousMillis;


/* USER CODE END 0 */

/**
  * @brief  The application entry point.
  * @retval int
  */
int main(void)
{
  /* MCU Configuration--------------------------------------------------------*/

  /* Reset of all peripherals, Initializes the Flash interface and the Systick. */
  HAL_Init();

  /* Configure the system clock */
  SystemClock_Config();

/* Configure the peripherals common clocks */
  PeriphCommonClock_Config();

  /* Initialize all configured peripherals */
  MX_GPIO_Init();
  MX_DMA_Init();
  MX_I2C1_Init();
  MX_I2S1_Init();
  MX_I2S2_Init();
  /* USER CODE BEGIN 2 */

  initSin();

  InitIO();
  CodecInit(&hi2c1);

  InitDSP(44000, &hi2s1, &hi2s2); //44117 is in IOC file

  /* USER CODE END 2 */

  /* Infinite loop */
  /* USER CODE BEGIN WHILE */
  while (1)
  {

	IOUpdate();
	DSPUpdate(&hi2s1);

    /* USER CODE END WHILE */

    /* USER CODE BEGIN 3 */


  }
  /* USER CODE END 3 */
}

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
/* USER CODE BEGIN 4 */

void HAL_GPIO_EXTI_Callback(uint16_t GPIO_Pin){

  /* Prevent unused argument(s) compilation warning */
  uint32_t currentMillis = HAL_GetTick();
  UNUSED(GPIO_Pin);


  if(GPIO_Pin == RotEncoderButton_Pin && (currentMillis - previousMillis > 100)){
	  ButtonInterrupt();
  }

  if(GPIO_Pin == RotEncoderInA_Pin || GPIO_Pin == RotEncoderInB_Pin){
	  RotaryEncoderInterrupt();
  }

  previousMillis = currentMillis;

}

/* USER CODE END 4 */
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


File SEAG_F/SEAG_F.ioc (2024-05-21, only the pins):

Mcu.UserName=STM32F722RCTx
PA10.GPIO_Label=ToggleInput3
PA10.Signal=GPIO_Input
PA11.GPIO_Label=ToggleInput2
PA11.Signal=GPIO_Input
PA12.GPIO_Label=ToggleInput1
PA12.Signal=GPIO_Input
PA13.Signal=SYS_JTMS-SWDIO
PA14.Signal=SYS_JTCK-SWCLK
PA15.GPIO_Label=ToggleInput8
PA15.Signal=GPIO_Input
PA4.Signal=I2S1_WS
PA5.Signal=I2S1_CK
PA7.Signal=I2S1_SD
PA9.GPIO_Label=ToggleInput4
PA9.Signal=GPIO_Input
PB12.Signal=I2S2_WS
PB13.Signal=I2S2_CK
PB6.Signal=I2C1_SCL
PB7.Signal=I2C1_SDA
PC0.GPIO_Label=ShiftRegLBarDat
PC0.Signal=GPIO_Output
PC1.Signal=I2S2_SD
PC10.GPIO_Label=ToggleInput7
PC10.Signal=GPIO_Input
PC11.GPIO_Label=ToggleInput6
PC11.Signal=GPIO_Input
PC12.GPIO_Label=ToggleInput5
PC12.Signal=GPIO_Input
PC13.GPIO_Label=ShiftRegFDat
PC13.Signal=GPIO_Output
PC14-OSC32_IN.GPIO_Label=ShiftRegFStoClk
PC14-OSC32_IN.Signal=GPIO_Output
PC15-OSC32_OUT.GPIO_Label=ShiftRegFClk
PC15-OSC32_OUT.Signal=GPIO_Output
PC2.GPIO_Label=ShiftRegLBarStoClk
PC2.Signal=GPIO_Output
PC3.GPIO_Label=ShiftRegLBarClk
PC3.Signal=GPIO_Output
PC4.Signal=I2S1_MCK
PC6.GPIO_Label=RotEncoderInA
PC6.Signal=GPXTI6
PC7.GPIO_Label=RotEncoderInB
PC7.Signal=GPXTI7
PC8.GPIO_Label=RotEncoderButton
PC8.Signal=GPXTI8
PH0-OSC_IN.Signal=RCC_OSC_IN
PH1-OSC_OUT.Signal=RCC_OSC_OUT

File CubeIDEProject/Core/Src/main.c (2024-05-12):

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
/* Includes ------------------------------------------------------------------*/
#include "main.h"

/* USER CODE BEGIN Includes */

/*kan seppe pushen wie weet */

/* USER CODE END Includes */

/* USER CODE BEGIN PD */

#define AUDIO_BUFFER_SIZE 128

/* USER CODE END PD */

I2C_HandleTypeDef hi2c1;

I2S_HandleTypeDef hi2s3;
DMA_HandleTypeDef hdma_spi3_rx;

UART_HandleTypeDef hlpuart1;

TIM_HandleTypeDef htim6;

/* USER CODE BEGIN PV */


SampleType adcBuf[AUDIO_BUFFER_SIZE];
SampleType dacBuf[AUDIO_BUFFER_SIZE];

static volatile SampleType *inBufPointer;
static volatile SampleType *outBufPointer = &dacBuf[0];

uint8_t dataReadyFlag;
/* USER CODE END PV */

void SystemClock_Config(void);
static void MX_GPIO_Init(void);
static void MX_DMA_Init(void);
static void MX_LPUART1_UART_Init(void);
static void MX_TIM6_Init(void);
static void MX_I2C1_Init(void);
static void MX_I2S3_Init(void);
/* USER CODE BEGIN 0 */

void processBuffer(const SampleType* input, SampleType* output, size_t bufferLength) {
    for (int i = 0; i < bufferLength; i++) {
        //output[i] = i;
        // output[i] = (uint16_t)(((float)(input[i])) / 4095.0f * 227.0f);
    }
}

//Called when first half of buffer is filled
void HAL_I2S_RxHalfCpltCallback(I2S_HandleTypeDef *hi2s){

	inBufPointer = &adcBuf[0];
	outBufPointer = &dacBuf[0];

	processBuffer(adcBuf, dacBuf, AUDIO_BUFFER_SIZE/2);

	//HAL_GPIO_TogglePin(SampleFreqOutClk_GPIO_Port, SampleFreqOutClk_Pin);

	dataReadyFlag = 1;

}

void HAL_I2S_RxCpltCallback(I2S_HandleTypeDef *hi2s){

	inBufPointer = &adcBuf[AUDIO_BUFFER_SIZE/2];
	outBufPointer = &dacBuf[AUDIO_BUFFER_SIZE/2];

	//processBuffer((SampleType*)(adcBuf+AUDIO_BUFFER_SIZE/2), (SampleType*)(dacBuf+AUDIO_BUFFER_SIZE/2), AUDIO_BUFFER_SIZE/2);
	//HAL_GPIO_TogglePin(SampleFreqOutClk_GPIO_Port, SampleFreqOutClk_Pin);

	dataReadyFlag = 1;
}

/* USER CODE END 0 */

/**
  * @brief  The application entry point.
  * @retval int
  */
int main(void)
{
  /* MCU Configuration--------------------------------------------------------*/

  /* Reset of all peripherals, Initializes the Flash interface and the Systick. */
  HAL_Init();

  /* Configure the system clock */
  SystemClock_Config();

  /* USER CODE BEGIN SysInit */

  __enable_irq();
  //hdac1.State = HAL_DAC_STATE_RESET;


  /* USER CODE END SysInit */

  /* Initialize all configured peripherals */
  MX_GPIO_Init();
  MX_DMA_Init();
  MX_LPUART1_UART_Init();
  MX_TIM6_Init();
  MX_I2C1_Init();
  MX_I2S3_Init();
  /* USER CODE BEGIN 2 */



  HAL_TIM_Base_Start(&htim6);

  InitDSP();

  CodecInit(&hi2c1);

  for(int i = 0; i < AUDIO_BUFFER_SIZE;i++){
	  dacBuf[i] = i;
  }

  HAL_Delay(1);

  HAL_I2S_Receive_DMA(&hi2s3, (uint16_t*)&adcBuf[0], AUDIO_BUFFER_SIZE/2);
  //HAL_I2S_Transmit_DMA(&hi2s3, (uint16_t*)&dacBuf[0], AUDIO_BUFFER_SIZE);

  /* USER CODE END 2 */

  /* Infinite loop */
  /* USER CODE BEGIN WHILE */
  while (1)
  {


	  //HAL_GPIO_TogglePin(LD2_GPIO_Port, LD2_Pin);
	  //HAL_GPIO_TogglePin(KnipperLedje_GPIO_Port, KnipperLedje_Pin);


      //uint16_t timerValue = __HAL_TIM_GET_COUNTER(&htim16);

      //float sinVal = (sin( (float)timerValue/3863*2*M_PI)+1)/2 *3.3;
      //uint32_t dacOutput = (uint32_t)(sinVal*4096)/3.3;

      //HAL_DAC_SetValue(&hdac1, DAC_CHANNEL_1, DAC_ALIGN_12B_R, 2048);
      //DAC1->DHR12R1 = dacOutput;
	  //uint16_t data = 0x55;



      /*
      if(timerValue == 0){

    	  TimerCallback(&hadc1, &hlpuart1, &hdac1);

    	  //sprintf(msg, "%hu\r\n", timerValue);
    	  //HAL_UART_Transmit(&hlpuart1, (uint8_t*)msg, strlen(msg), HAL_MAX_DELAY);

		  //sprintf(msg, "%d\n", (int)dacOutput);
		  //HAL_UART_Transmit(&hlpuart1, (uint8_t*)msg, strlen(msg), HAL_MAX_DELAY);

      }
       */


    /* USER CODE END WHILE */

    /* USER CODE BEGIN 3 */
  }
  /* USER CODE END 3 */
}

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


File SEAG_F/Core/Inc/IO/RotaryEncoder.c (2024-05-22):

/*
 * RotaryEncoder.c
 *
 *  Created on: may 6, 2024
 *      Author: Floran
 */


#include "RotaryEncoder.h"

uint8_t rot_old_state =0;
uint8_t rot_new_state=0;


uint8_t rot_get_state(RotaryEncoder_t* rotEncoder) {
	return (uint8_t)( (HAL_GPIO_ReadPin(rotEncoder->portB, rotEncoder->pinB) << 1)
                	| (HAL_GPIO_ReadPin(rotEncoder->portA, rotEncoder->pinA)) );
}

//deze functie overloopt 4 fase van een rotery encoder, eerst stijgen de klokflank 1 van de 2 fase beide hoog
//3de fase de eerste die hoog was terug laag word en 4de fase allebei laag
void rot_intrupt(RotaryEncoder_t* rotEncoder){

	  rot_new_state = rot_get_state(rotEncoder);
	  		// Check transition
	  if (rot_old_state == 3 && rot_new_state == 2) {        // 3 -> 2 transition
		  rotEncoder->currentPos++;
	  } else if (rot_old_state == 2 && rot_new_state == 0) { // 2 -> 0 transition
		  rotEncoder->currentPos++;
	  } else if (rot_old_state == 0 && rot_new_state == 1) { // 0 -> 1 transition
		  rotEncoder->currentPos++;
	  } else if (rot_old_state == 1 && rot_new_state == 3) { // 1 -> 3 transition
		  rotEncoder->currentPos++;
	  } else if (rot_old_state == 3 && rot_new_state == 1) { // 3 -> 1 transition
		  rotEncoder->currentPos--;
	  } else if (rot_old_state == 1 && rot_new_state == 0) { // 1 -> 0 transition
		  rotEncoder->currentPos--;
	  } else if (rot_old_state == 0 && rot_new_state == 2) { // 0 -> 2 transition
		  rotEncoder->currentPos--;
	  } else if (rot_old_state == 2 && rot_new_state == 3) { // 2 -> 3 transition
		  rotEncoder->currentPos--;
	  }
	  rot_old_state = rot_new_state;
}

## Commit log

2024-02-21 Added Cube project, made blinking LED
2024-02-22 configured ADC0 pin
2024-02-25 Configured DAC, ADC, TIM. Added preliminary files
2024-02-29 de taak van profesionele competenties toegevoegd met deadline 6/3 added SEAG.md
2024-02-29 incoming sample, directly placed on DAC
2024-02-29 Added DMA support, ADC works, DAC needs work. Added schedule to obsidian under folder 'Seminaries'
    [planning_audio_generator.xlsx]
2024-02-29 Tried some stuff with ioc file, DAC DMA doesnt work
2024-03-02 Added datasheets and footprint reference to obsidian. Drew schematic for MCU decoupling and crystal circuitry
    [MCU.kicad_sch, PowerSupply.kicad_sch, SEAG.kicad_pcb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]
2024-03-02 Added power supply and serial link header to PCB schematic
    [MCU.kicad_sch, PowerSupply.kicad_sch, SEAG.kicad_sch]
2024-03-05 Added 'AudioFiltering' and 'Codec' sheets to PCB schematic, started PCB layout with decouple caps and MCU. The codec in sheet 'Codec' is wrong, placed for testing
    [AudioFiltering.kicad_sch, Codec.kicad_sch, MCU.kicad_sch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]
2024-03-07 seminaries documentatie: excel planning, temp bom lijst in foot prints en stakeholder analyse
    [planning_audio_generator.xlsx]
2024-03-07 Added ESD protection, extra filtering with ferrite bead
    [AudioFiltering.kicad_sch, MCU.kicad_sch, PowerSupply.kicad_sch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]
2024-03-08 Small note in PCB Design, about planes on PCB
2024-03-31 Finished PCB, stil uncertain about couple things
    [AudioFiltering.kicad_sch, Codec.kicad_sch, IO.kicad_sch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]
2024-04-01 PCB rev 2
    [AudioFiltering.kicad_sch, Codec.kicad_sch, IO.kicad_sch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]
2024-04-01 on pcb
2024-04-01 Added rotary encoder screw terminal
    [AudioFiltering.kicad_sch, IO.kicad_sch, SEAG.kicad_pcb]
2024-04-02 gezevert aan pcb
    [SEAG.kicad_pcb]
2024-04-09 Slight PCB changes
    [IO.kicad_sch, MCU.kicad_sch, PowerSupply.kicad_sch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]
2024-04-17 Added header
    [AudioFiltering.kicad_sch, IO.kicad_sch, MCU.kicad_sch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]
2024-04-20 Generated gerber files, also ordered PCB
    [SEAG-B_Mask.gbr, SEAG-B_Paste.gbr, SEAG-B_Silkscreen.gbr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]
2024-04-24 Small changes to IO code
    [SEAG.kicad_pcb]
2024-04-24 Fixed errors in IO files
    [IO.c]
2024-04-30 Made stm32F722 project. Added reverb filter
    [SEAG-B_Mask.gbr, SEAG-B_Paste.gbr, SEAG-B_SignalPlane.gbr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]
2024-05-06 Rotary Encoder struct
2024-05-12 code for pcb
    [SEAG.kicad_pcb]
2024-05-13 Added Filters.h & Filters.c
2024-05-15 Sent 0 to right channel in process buffer. Set index 0 of selected filter with toggle (not tested)
2024-05-17 Switched I²S and DMA to 16 bit
2024-05-18 added low pass filter & distortion, both not working
    [DSP.c]
2024-05-19 Working reverb filter, added low-high pass
2024-05-20 Added flanger, chorus (both kinda scuffed), added methods to change filter level. added Filter struct to represent a filter with its methods
    [AudioFiltering.kicad_sch, MCU.kicad_sch]
2024-05-23 toevoeging wav files, datasheet io, 2D tekeningen
    [SEAGDoos.dwg, SEAG_doos.dxf, SEAGdoos.obj]
2024-05-25 Bolt titles in README

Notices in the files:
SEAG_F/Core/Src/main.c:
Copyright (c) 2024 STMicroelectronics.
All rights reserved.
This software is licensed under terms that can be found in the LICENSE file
